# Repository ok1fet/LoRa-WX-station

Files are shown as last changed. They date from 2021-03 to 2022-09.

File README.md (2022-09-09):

<h1>LoRa-APRS-WX-station</h1>
<p>Záměrem bylo vytvořit jednoduchou malou meteosondu. Aby byla levná, aby ji bylo možné bez obav na kopci přidělat na strom :)</p>
<ul>
<p>Informace ze sondy mají sloužit pro piloty paraglidingu, které zajímá hlavně směr a rychlost větru. Proto byla programu věnována značná pozornost. Měření probíhá každých 20 sekund a data se agregují po 5 minutách. Navíc se spočítá průměrná hodnota větru a vyhodnotí se maximální nárazy větru. Směr větru se měří <a href="https://en.wikipedia.org/wiki/Yamartino_method">Yamartino metodou.</a></p>
</ul>  
<p>Data se ukládají na cloudové uložiště na serveru www.aprs.fi.</p>
<p>Pro měření rychlosti a směru větru jsou použita čidla k meteostanici WH1080, která jsou na našem trhu dostupná jako náhradní díly za rozumný peníz.</p>
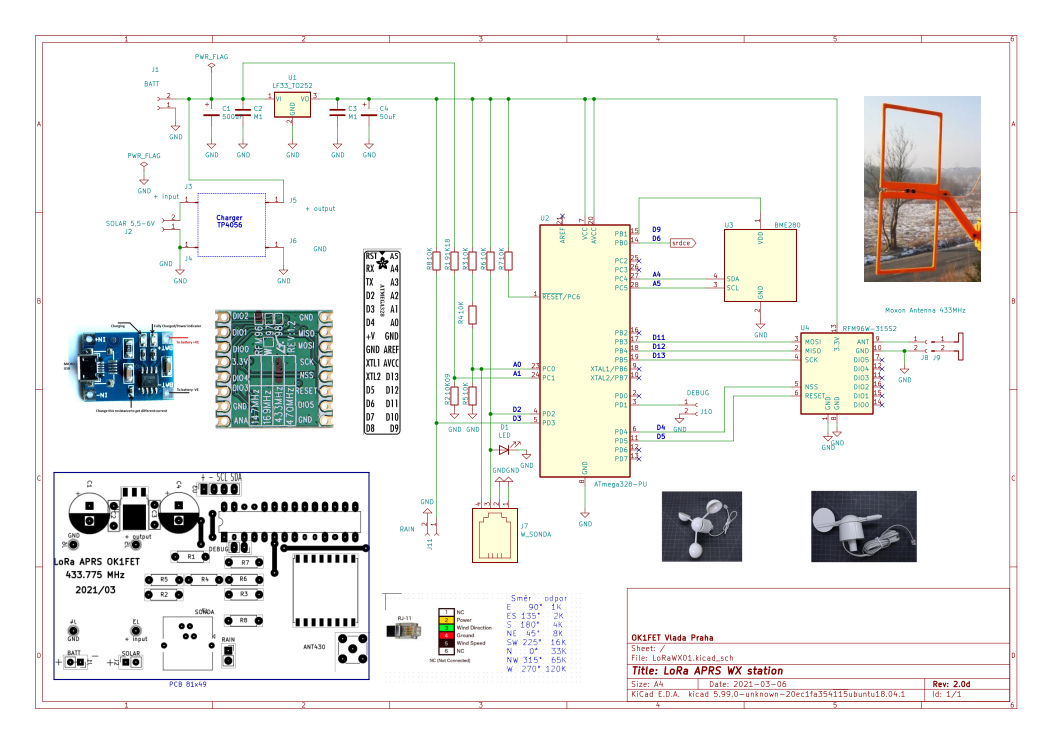
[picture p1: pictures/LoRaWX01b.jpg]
schema
</p>

<p>Meteorologická stanice <a href="http://cukrak.wz.cz/"> Cukrák.</a> Zdrojová data na www.aprs.fi/ok1fet-4.</a></p>
<p>Meteorologická stanice <a href="http://jevinka.wz.cz/"> Jeviněves.</a> Zdrojová data na www.aprs.fi/ok1fet-5.</a></p>
<p>Meteorologická stanice <a href="http://revnicov.wz.cz/"> Řevničov.</a> Zdrojová data na www.aprs.fi/ok1fet-14.</a></p>
<p> Moxon antena na 433MHz. <a href="https://www.thingiverse.com/thing:2068392/files">Zdrojová data</a> pro 3D printer na Thingiverse.</a></p>

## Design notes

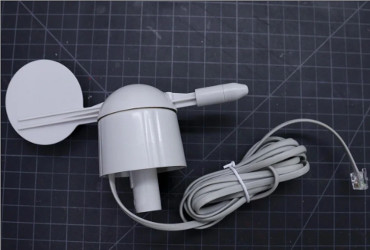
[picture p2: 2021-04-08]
pictures/winddirection.jpg

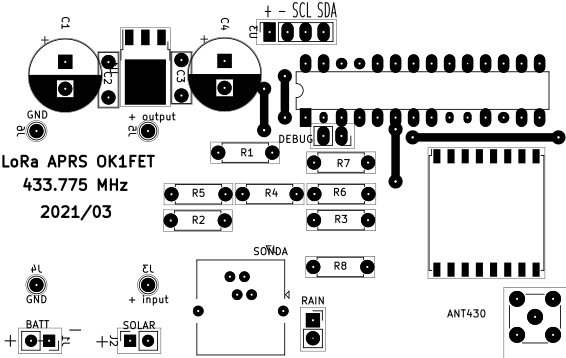
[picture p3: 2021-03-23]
pictures/LoRa_top.jpg

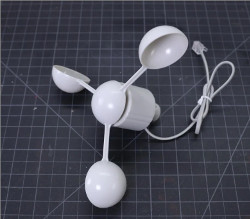
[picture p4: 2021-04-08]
pictures/anemometer.jpg

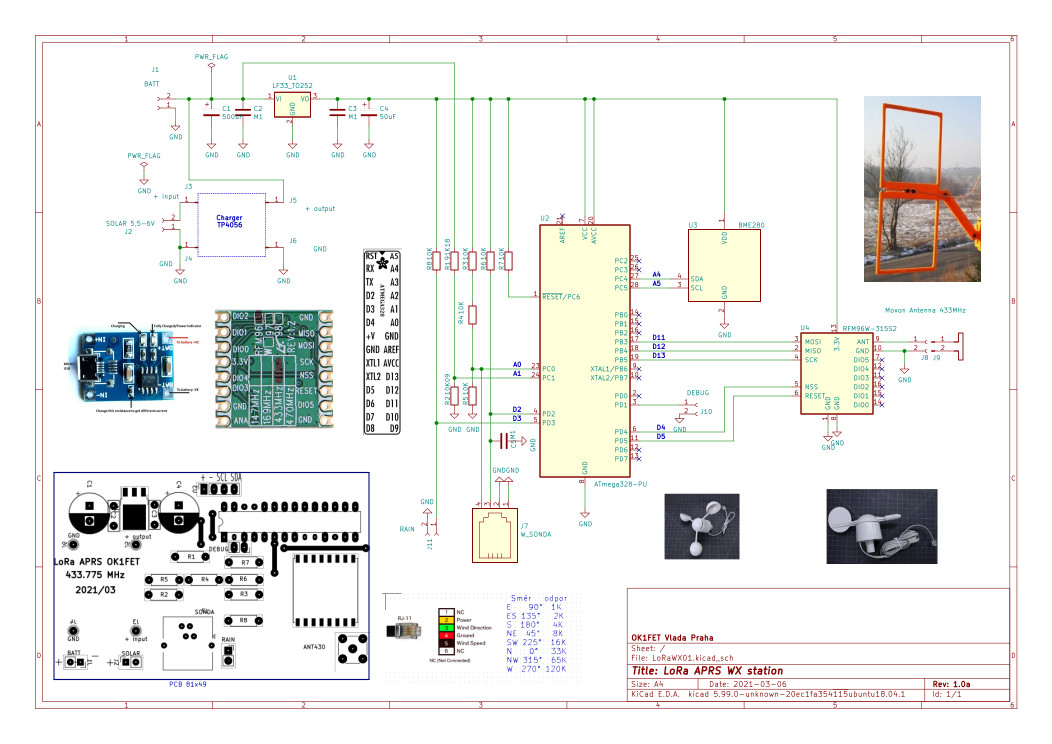
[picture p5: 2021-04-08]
pictures/LoRaWX1a.jpg

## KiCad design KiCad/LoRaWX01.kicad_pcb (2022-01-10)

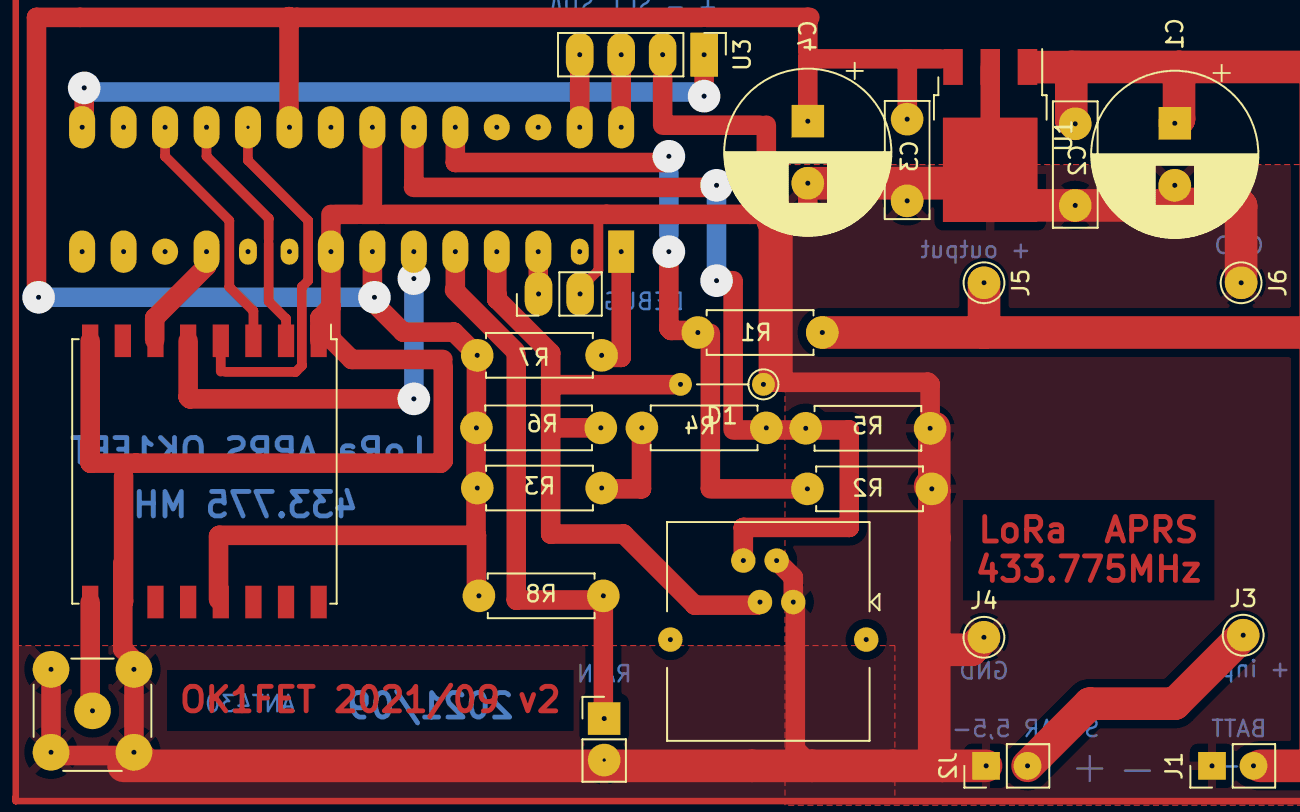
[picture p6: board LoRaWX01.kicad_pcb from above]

Board: 2 copper layers, 27 parts (1 on the bottom side), 20 nets.

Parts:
C1: 500uF; CP_Radial_D10.0mm_P3.80mm
C2: M1; C_Disc_D7.5mm_W2.5mm_P5.00mm
C3: M1; C_Disc_D7.0mm_W2.5mm_P5.00mm
C4: 50uF; CP_Radial_D10.0mm_P3.80mm
D1: LED; R_Axial_DIN0204_L3.6mm_D1.6mm_P5.08mm_Vertical
J1: BATT; PinHeader_1x02_P2.54mm_Vertical
J2: SOLAR 5,5-6V; PinHeader_1x02_P2.54mm_Vertical
J3: + input; Pin_D1.0mm_L10.0mm
J4, J6: GND; Pin_D1.0mm_L10.0mm
J5: + output; Pin_D1.0mm_L10.0mm
J7: W_SONDA; RJ14_Connfly_DS1133-S4_Horizontal
J8: ANT-433; SMA_Molex_73251-2200_Horizontal
J10: DEBUG; PinHeader_1x02_P2.54mm_Vertical
J11: RAIN; PinHeader_1x02_P2.54mm_Vertical
R1: 91K18; R_Axial_DIN0207_L6.3mm_D2.5mm_P7.62mm_Horizontal
R2: 10K09; R_Axial_DIN0207_L6.3mm_D2.5mm_P7.62mm_Horizontal
R3, R4, R5, R6, R7, R8: 10K; R_Axial_DIN0207_L6.3mm_D2.5mm_P7.62mm_Horizontal
U1: LF33_TO252; TO-252-3_TabPin2
U2: ATmega328-PU; DIP-28_W7.62mm
U3: BME280; PinHeader_1x04_P2.54mm_Vertical
U4: RFM96W-315S2; HOPERF_RFM9XW_SMD

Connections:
GND: C1.2, C2.2, C3.2, C4.2, D1.1 (K), J1.1, J2.1, J4.1, J6.1, J7.1, J7.2, J8.2, J10.2, J11.2, R2.2, R5.2, U1.2 (GND), U2.8 (GND), U2.22 (GND), U3.2 (GND), U4.1 (GND), U4.8 (GND), U4.10 (GND)
unnamed: C1.1, C2.1, J1.2, J5.1, R1.1, U1.1 (VI)
unnamed: C3.1, C4.1, R3.1, R6.1, R7.1, R8.1, U1.3 (VO), U2.7 (VCC), U2.20 (AVCC), U4.13 (3.3V)
unnamed: D1.2 (A), J7.3, R6.2, U2.4 (PD2)
unnamed: J2.2, J3.1
unnamed: J7.4, R4.2, R5.1, U2.23 (PC0)
unnamed: J8.1, U4.9 (ANT)
unnamed: J10.1, U2.3 (PD1)
unnamed: J11.1, R8.2, U2.5 (PD3)
unnamed: R1.2, R2.1, U2.24 (PC1)
unnamed: R3.2, R4.1
unnamed: R7.2, U2.1 (~RESET~/PC6)
unnamed: U2.6 (PD4), U4.5 (NSS)
unnamed: U2.11 (PD5), U4.6 (RESET)
unnamed: U2.15 (PB1), U3.1 (VDD)
unnamed: U2.17 (PB3), U4.3 (MOSI)
unnamed: U2.18 (PB4), U4.2 (MISO)
unnamed: U2.19 (PB5), U4.4 (SCK)
unnamed: U2.27 (PC4), U3.4 (SDA)
unnamed: U2.28 (PC5), U3.3 (SCL)

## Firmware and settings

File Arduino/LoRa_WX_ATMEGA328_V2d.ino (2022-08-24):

/* V2d
 * uP ATMEGA328 ja pouzivam bootloader FIO
  * 
 * Pin
 * RFM96  UNO   TTGO
 * SCK    D13   5
 * MISO   D12   19
 * MOSI   D11   27
 * NSS    D4    18    lora_PNSS
 * RST    D5    23    lora_PReset
 * 
 * bme280
 * SCL    A5    
 * SDA    A4
 * 
 */
///////////////////////////////////////////////////////////
//#include "config.h"
#include <LowPower.h>
unsigned int PeriodeCounterSleep = 0; // 2 kdyz je stejne jako "timer" spusti mereni v prvni cyklu
unsigned int timer = 2;               // 2 timer * 8 (SLEEP_8S) = cas buzeni ATMEGA328 sekundy 2 x 8=16sekund
int pocetmereniAgregace = 15;         //15 kolik mereni nez se udela agragace dat cca 5minut
unsigned int cyklus = 0;              //15 kdyz je stejne jako "pocetmereniAgregace" spusti agregace v prvni cyklu

//LoRa
const byte lora_PNSS   = 4;  // 18 pin number where the NSS line for the LoRa device is connected.
const byte lora_PReset = 5;  // 23 pin where LoRa device reset line is connected
const byte PLED1 = 6;        // pin number for LED on Tracker neni zapojeno
#include <SPI.h>
#include "LoRaTX.h"
#include <Wire.h>
String Outstring=""; 
   

// BME280
#include <Adafruit_Sensor.h>
#include <Adafruit_BME280.h>
Adafruit_BME280 bme;
float wind, temp, tempf, humi, pres, pres1;
int napajeni = 9; //pin 15 slouzi pro snizeni spotreby napaji se jen kdyz probiha mereni

// wind speed aneometer
float DataSpeed[30];  // pole pro data
float WindSpeedMax;
float WindSpeedAvg;
int anopin = 3;       // PIN for anemometer input
int InterruptCounter;
float WindSpeed;
int WindSpeedAvgA;// rychlost vetru prumer archiv
int WindSpeedMaxA;// rychlost vetru maximalni archiv
float  wsm,wsa;
volatile unsigned long ContactBounceTime; // Timer to avoid contact bounce in interrupt routine

//wind direction smerova ruzice
#include "Yamartino.h"
Yamartino yamartino(2);   // pocet mereni za sekundu
const int SensorPin = 2;  // Define Interrupt Pin (2 or 3 @ Arduino Uno)
int i=0;

#include "AverageAngle.h"
float DataSmer[30]; // pole pro data
float wdn;  //promena pro prepocet z ADC na uhly
int wd;   // hodnota AD prevodniku
int heading; // promena pro Yamartino knihovnu
float wda;    // WindDirectoryArchiv
float WindDirectoryAvg; // vystupni hodnota z AverageAngle
int pinWindDir = A0;//pin pro smer vetru

//mereni baterie
int voltPin = A1;
float vcc;
float predradnik;
float adc;
float napetiCPU = 1.1;   // hodnoto napajeciho napeti uProcesoru analogReference(INTERNAL)1.1V

char sentence[150];

int srdce = 8; //pin 14 vystup pro HW reset
int srdce_status = 0;

const char* station = "OK1XYZ-11>APRS:!5004.91N/01431.53E_"; // upravit call!!!!!
float ELEVATION = 224; // viska metru nad morem
float resistor1 = 90.92; // 90K pro 8,5V vstupni svorka 
float resistor2 = 10.08;  // 10Kohm na GND

/////////////////////////////////////////////////////////////////////////////////////////
void setup()
{
  analogReference(INTERNAL);
  predradnik = resistor2 / (resistor1 + resistor2);
  
  Serial.begin(9600);  
  Serial.println("start_v2d");// 
  delay(20);

  pinMode(napajeni, OUTPUT); // napajeni pro BME280

  pinMode(lora_PReset, OUTPUT);     // RFM98 reset line
  digitalWrite(lora_PReset, LOW);   // Reset RFM98
  pinMode (lora_PNSS, OUTPUT);      // set the slaveSelectPin as an output:
  digitalWrite(lora_PNSS, HIGH);
  pinMode(PLED1, OUTPUT);                                                          // for shield LED neni na pcb sviti pri TX
  
  SPI.begin();                                                                     // initialize SPI:
  SPI.setClockDivider(SPI_CLOCK_DIV2);
  SPI.setDataMode(SPI_MODE0);
  SPI.setBitOrder(MSBFIRST);
   
   lora_ResetDev();                                                                 // Reset the device
   lora_Setup();                                                                    // Do the initial LoRa Setup

// LoRa frequency calculation (sample for 434.4 MHz): 
// ------------------------------------
// 434400000/61.03515625 = 71172096
// 71172096 (DEC) = 6C 99 99 (HEX)  
// 6C 99 99 (HEX) = 108 153 153 (DEC)  

   lora_SetFreq(108, 113, 153);  // Set the LoRa frequency, 433.775 Mhz

   

pinMode(srdce, OUTPUT);  
}

///////////////////////////////////////////////////////////////////////////////////////
void loop(){
  
  while(PeriodeCounterSleep < timer){
  Serial.println("+");
  PeriodeCounterSleep++;
  delay(100);
  LowPower.powerDown(SLEEP_8S, ADC_OFF, BOD_OFF); 
   }
PeriodeCounterSleep = 0; 
/*****************************************************************
                     5 minut cyklus Agregace dat
*****************************************************************/
if (cyklus >= pocetmereniAgregace){
Serial.println("5 minut cyklus Agregace dat + odeslani dat LoRa"); 
/*****************************************************************/
digitalWrite(srdce, HIGH); 
digitalWrite(napajeni, HIGH); 
  for (i=0;i<cyklus;i++){
  //Serial.println(DataSpeed[i]); 
   WindSpeedAvg = (DataSpeed[i])+ WindSpeedAvg; // secte vsechny hodnoty v poly DataSpeed
  
  if ((DataSpeed[i]) > WindSpeedMax){     // pri listovani pole DataSpeed hleda maximalni hodnotu
  //Serial.println("Vyhodnoceni WindSpeedMax") ;
    WindSpeedMax=(DataSpeed[i]) ;     // zapise maximalni hodnotu do promene WindSpeedMax
  }
}
WindSpeedAvg = WindSpeedAvg / cyklus; // vypocita prumernou hodnotu WindSpeedAvg

/*****************************************************************/  
AverageAngle Smer(AverageAngle::DEGREES);
  Smer.reset();
  for (i=0;i<cyklus;i++){     //cyklus precte pole DataSmer a pomoci knihovny vypocitá průmerný úhel
      Smer.add(DataSmer[i]);
  }
  WindDirectoryAvg = Smer.getAverage();

/**************************************************************/  
// zmeri napeti 
  vcc = analogRead(voltPin);
// Convert to actual voltage (0 - 1.1 V internal)
  vcc = (vcc / 1024) * napetiCPU;
  vcc = vcc / predradnik;

  bme.begin(0x76); //address either 0x76 or 0x77
  bme.takeForcedMeasurement();
  temp = bme.readTemperature();
  humi = bme.readHumidity();
  pres = (bme.readPressure())/pow((1-ELEVATION/44330.0), 5.255)/10;// prepocet tlaku na hladinu more
  
  wda = Smer.getAverage();
  wsa = WindSpeedAvg;
  wsm = WindSpeedMax;
  digitalWrite(napajeni, LOW); 
  
   byte i;
   byte ltemp;
   tempf=(temp*1.8)+32; // celsius to fahrenheit

    
// prezentace dat
  Serial.println("") ;
  Serial.print("Average Direction = ");
  Serial.print(wda,0); 
  Serial.println("°") ;

  Serial.print("Wind Speed Avg    = ");
  Serial.print(wsa,1);       //Speed in mph
  Serial.println(" mph"); 
    
  Serial.print("Wind Speed Max    = ");
  Serial.print(wsm,1);       //Speed in mph
  Serial.println(" mph");

  Serial.print("Napeti            = ");
  Serial.print(vcc);
  Serial.println("V");
  
  Serial.print("Temperature       = ");
  Serial.print(temp,1);
  Serial.println("°C");
  
  Serial.print("Humidity          = ");
  Serial.print(humi,0);
  Serial.println("%");
  pres1=pres/10;
  Serial.print("Pressure to sea   = ");
  Serial.print(pres1,1);
  Serial.println("hPa");
  


// odeslani dat pres LoRa 
   Outstring = (station); 
   if(wda<99) { Outstring += "0"; }
   if(wda<9)  { Outstring += "0"; }
   Outstring += String(wda,0);
   Outstring += "/";
   if(wsa<99) { Outstring += "0"; }
   if(wsa<9)  { Outstring += "0"; }
   Outstring += String(wsa,0);
   Outstring += ("g");
   if(wsm<99) { Outstring += "0"; }
   if(wsm<9)  { Outstring += "0"; }
   Outstring += String(wsm,0);
   Outstring += ("t");
   if(tempf<99) { Outstring += "0"; }
   if(tempf<9) { Outstring += "0"; }
   Outstring += String(tempf,0);
   Outstring += ("h");
   Outstring += String(humi,0);
   Outstring += ("b");
   if(pres<999) { Outstring += "0"; }
   Outstring += String(pres,0);
   Outstring += ("_BATT=");
   Outstring += String(vcc,2);
   Outstring += ("V");

   if (srdce_status == 0){
    Outstring += ("_RESETd");
    srdce_status = 1;
   }

   Serial.print("sending: ");
   //Serial.println(Outstring);
   Outstring.replace(" ","");// wsa a wda pri zaukrohlovani obcas vkladji mezeru pred hodnotu!
   Serial.println(Outstring);
 

//LoRa
    ltemp = Outstring.length();
    lora_SetModem(lora_BW125, lora_SF12, lora_CR4_5, lora_Explicit, lora_LowDoptON);    // Setup the LoRa modem parameters
    lora_PrintModem();                                                                  // Print the modem parameters
    lora_TXStart = 0;
    lora_TXEnd = 0;
    for (i = 0; i <= ltemp; i++)
    {
    lora_TXBUFF[i] = Outstring.charAt(i);
    }
    i--;
    lora_TXEnd = i;    
    digitalWrite(PLED1, HIGH);  // LED ON on during sending
    
    Serial.print("ON AIR");

    lora_Send(lora_TXStart, lora_TXEnd, 60, 255, 1, 10, 17);  
    digitalWrite(PLED1, LOW);   // LED OFF after sending
    lora_TXBuffPrint(0);
//konec vysilani dat LoRa     
 
    Outstring = "";
    cyklus = 0;
    WindSpeedAvg = 0;
    WindSpeedMax = 0;
    digitalWrite(srdce, LOW); 
   
/**************konec 5 minutoveho i cyklu************************************************/  
}
/*****************************************************************
                 standardni mereni kazdych 20 sekund
*****************************************************************/
    Serial.print(cyklus);
    Serial.println(" - standardni mereni kazdych 20 sekund");
    digitalWrite(srdce, HIGH); 
    mereniWindSpeed();
    DataSpeed[cyklus]=(WindSpeed);// zapise hodnotu do pole DataSpeed

    heading = getWindDirection();
    yamartino.add(heading);
    DataSmer[cyklus] = (yamartino.averageHeading());// zapise hodnotu do pole DataSmer

    Serial.print(WindSpeed,1); //Speed in mph
    Serial.println(" mph");
    Serial.print(yamartino.averageHeading(),0);
    Serial.println("°") ;
    Serial.println("ulozeno do datoveho pole");
    Serial.println("goto Sleeping...");
    digitalWrite(srdce, LOW); 
    delay (100);


cyklus++;
}// endloop
/*****************************************************************
                 mereni rychlosti vetru
*****************************************************************/
void mereniWindSpeed() {
    InterruptCounter = 0; // Set Rotations count to 0 ready for calculations 
    attachInterrupt(digitalPinToInterrupt(SensorPin), countup, FALLING);
    delay(3000);// Wait 3 seconds to average 
    detachInterrupt(digitalPinToInterrupt(SensorPin));
//  WindSpeed = (float)InterruptCounter / 3 * 1.492;// prepocet na Mph 0,497333333(prepocet z ms na Mph) / 3 (delka mereni v sekundach)
//  WindSpeed = (float)InterruptCounter * 0.3 ;// vranova konstanta --> ukazuje mene!!!
// prepocet 3 vteriny rotace na MPh
         if ((float)InterruptCounter   <= 42){WindSpeed = (float)InterruptCounter /3 * 0.77;}
    else if ((float)InterruptCounter   <= 45){WindSpeed = (float)InterruptCounter /3 * 0.82;}
    else if ((float)InterruptCounter   <= 48){WindSpeed = (float)InterruptCounter /3 * 0.87;}
    else if ((float)InterruptCounter   <= 51){WindSpeed = (float)InterruptCounter /3 * 0.90;}
    else if ((float)InterruptCounter   <= 54){WindSpeed = (float)InterruptCounter /3 * 0.94;}
    else if ((float)InterruptCounter   >= 55){WindSpeed = (float)InterruptCounter /3 * 0.89;}
}

void countup() {
if ((millis() - ContactBounceTime) > 15 ) { // osetreni zakmitavani jazyckoveho kontaktu 
InterruptCounter++;
ContactBounceTime = millis(); 
}   
  
}
/*****************************************************************
                 mereni smeru vetru
*****************************************************************/
float getWindDirection() {

   wd =  analogRead(pinWindDir);
delay(10);
// Serial.print("WindDir");// pouzit pro kalibraci smerove ruzice
// Serial.println(wd);

      if      (wd < 150) wdn =  90; 
      else if (wd < 270) wdn = 135; 
      else if (wd < 400) wdn = 180; 
      else if (wd < 580) wdn =  45; 
      else if (wd < 760) wdn = 225; 
      else if (wd < 890) wdn =   0; 
      else if (wd < 960) wdn = 315; 
      else if (wd < 1000)wdn = 270;       
  
  return wdn;  
}
/* REMARKS
zapise bootloader nastavi pojistky 8MHz vnitrni hodiny na pin19 D13 blika 1S programovat Arduino FIO
avrdude -c arduino -p m328p -b 19200 -P /dev/ttyACM0 -U flash:w:ATmegaBOOT_168_atmega328_pro_8MHz.hex -Uefuse:w:0xFD:m -Uhfuse:w:0xDA:m -Ulfuse:w:0xE2:m

https://weather.gladstonefamily.net/aprswxnet.html
 
Field  Meaning
CW0003  Your CW number
>APRS,TCPIP*: Boilerplate
/241505z  The ddhhmm in UTC of the time that you generate the report. However, the timestamp is pretty much ignored by everybody as it is assumed that your clock is not set correctly! If you want to omit this field, then just send an exclamation mark '!' instead.
4220.45N/07128.59W  Your location. This is ddmm.hh -- i.e. degrees, minutes and hundreths of minutes. The Longitude has three digits of degrees and leading zero digits cannot be omitted.
_032  The direction of the wind from true north (in degrees).
/005  The average windspeed in mph
g008  The maximum gust windspeed in mph (over the last five minutes)
t054  The temperature in degrees Farenheit -- if not available, then use '...' Temperatures below zero are expressed as -01 to -99.
r001  The rain in the last 1 hour (in hundreths of an inch) -- this can be omitted
p078  Rain in the last 24 hours (in hundreths of an inch) -- this can be omitted
P044  The rain since the local midnight (in hundreths of an inch) -- this can be omitted
h50 The humidity in percent. '00' => 100%. -- this can be omitted.
b10245  The barometric pressure in tenths of millbars -- this can be omitted. This is a corrected pressure and not the actual (station) pressure as measured at your weatherstation. The pressure is adjusted according to altimeter rules -- i.e. the adjustment is purely based on station elevation and does not include temperature compensation.
 
OK1FET-5>APN100,TCPIP*:=5020.55N/01419.98E_045/002g...t045r...p...P000h55b.....eESP8266
 
ANT 433MHz
https://quadmeup.com/3d-printed-433mhz-moxon-antenna-with-arm-and-snap-mount/
https://www.thingiverse.com/thing:2068392/files
 
lf33
http://robodoupe.cz/2012/vezmu-lf33-a-zadny-problem/
https://ok1kvk.cz/clanek/2017/LF33-aneb-ctete-datasheety/

Lithium Battery charging tp4056
https://www.buildcircuit.com/how-to-use-micro-usb-5v-1a-lithium-battery-charging-board-charger-module/
http://jimlaurwilliams.org/wordpress/?p=4731

bme280 how AMSL
https://www.meteocercal.info/forum/Thread-How-to-get-the-sea-level-pressure-with-BMP280

inspirace
https://www.instructables.com/Solar-Powered-WiFi-Weather-Station-V30/?utm_source=newsletter&utm_medium=email

prevest WGS84  N 50°10.84313', E 13°53.28152'zapsat jako 5010.84N/01353.28E

 */

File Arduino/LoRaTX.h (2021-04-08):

/*
**************************************************************************************************
ProMiniLoRaTracker_V1 Programs

Copyright of the author Stuart Robinson - 02/07/2015 15:00

These programs may be used free of charge for personal, recreational and educational purposes only.

This program, or parts of it, may not be used for or in connection with any commercial purpose without
the explicit permission of the author Stuart Robinson.

The programs are supplied as is, it is up to individual to decide if the programs are suitable for the
intended purpose and free from errors.
**************************************************************************************************
*/


//http://www.kh-gps.de/LoRa_WX.htm

/*
**************************************************************************************************
Variable definitions
**************************************************************************************************
*/

//byte Variables
byte  lora_TXStart;				//start of packet data in TXbuff
byte  lora_TXEnd;				//end of packet data in TXbuff
byte  lora_FTXOK;				//flag, set to 1 if TX OK
byte  lora_TXPacketType;		//type number of packet to send
byte  lora_TXDestination;		//destination address of packet to send
byte  lora_TXSource;			//source address of packet received
byte  lora_FDeviceError;		//flag, set to 1 if RFM98 device error
byte  lora_TXPacketL;			//length of packet to send, includes source, destination and packet type.

//byte arrays
byte  lora_TXBUFF[128];			//buffer for packet to send

//Integer variables, more than byte
long lora_TXpacketCount;		//count of packets sent

//Float Variables
double lora_Frequency;			//last programmed frequency



/*
**************************************************************************************************
Constant definitions
**************************************************************************************************
*/

//LoRa names for bandwidth settings
const byte lora_BW7_8 = 0;      //7.8khz
const byte lora_BW10_4 = 16;    //10.4khz
const byte lora_BW15_6 = 32;    //15.6khz
const byte lora_BW20_8 = 48;    //20.8khz
const byte lora_BW31_2 = 64;    //31.2khz
const byte lora_BW41_7 = 80;    //41.7khz
const byte lora_BW62_5 = 96;    //62.5khz
const byte lora_BW125 = 112;    //125khz
const byte lora_BW250 = 128;    //250khz
const byte lora_BW500 = 144;    //500khz

//Spreading Factors
const byte lora_SF6 = 6;
const byte lora_SF7 = 7;
const byte lora_SF8 = 8;
const byte lora_SF9 = 9;
const byte lora_SF10 = 10;
const byte lora_SF11 = 11;
const byte lora_SF12 = 12;

//LORA names for coding rate settings
const byte lora_CR4_5 = 2;	//4:5
const byte lora_CR4_6 = 4;	//4:6
const byte lora_CR4_7 = 6;	//4:7
const byte lora_CR4_8 = 8;	//4:8

//LORA Header Settings
const byte lora_Explicit    = 0;	//Use to set explicit header
const byte lora_Implicit    = 1;	//Use to set implicit header

//Misc definitions
const byte lora_Deviation = 0x52;
const byte lora_LowDoptON = 0x08;       //value to turn low data rate optimization on
const byte lora_LowDoptOFF = 0x00;      //value to turn low data rate optimization off
const byte lora_PrintASC = 0;           //value to cause buffer print to appear as ASCII
const byte lora_PrintNum = 1;           //value to cause buffer print to appear as decimal numbers
const byte lora_PrintHEX = 2;           //value to cause buffer print to appear as hexadecimal numbers


//SX1278 Register names
const byte lora_RegFifo = 0x00;
const byte lora_WRegFifo = 0x80;
const byte lora_RegOpMode = 0x01;
const byte lora_RegFdevLsb = 0x05;
const byte lora_RegFrMsb = 0x06;
const byte lora_RegFrMid = 0x07;
const byte lora_RegFrLsb = 0x08;
const byte lora_RegPaConfig = 0x09;
const byte lora_RegOcp = 0x0B;
const byte lora_RegLna = 0x0C;
const byte lora_RegFifoAddrPtr = 0x0D;
const byte lora_RegFifoTxBaseAddr = 0x0E;
const byte lora_RegIrqFlagsMask = 0x11;
const byte lora_RegIrqFlags = 0x12;
const byte lora_RegRxNbBytes = 0x13;
const byte lora_RegRxHeaderCntValueMsb = 0x14;
const byte lora_RegRxHeaderCntValueLsb = 0x15;
const byte lora_RegRxPacketCntValueMsb = 0x16;
const byte lora_RegRxPacketCntValueLsb = 0x17;
const byte lora_RegPktSnrValue = 0x19;
const byte lora_RegPktRssiValue = 0x1A;
const byte lora_RegRssiValue = 0x1B;
const byte lora_RegFsiMSB = 0x1D;
const byte lora_RegFsiLSB = 0x1E;
const byte lora_RegModemConfig1 = 0x1D;
const byte lora_RegModemConfig2 = 0x1E;
const byte lora_RegSymbTimeoutLsb = 0x1F;
const byte lora_RegPreambleLsb = 0x21;
const byte lora_RegPayloadLength = 0x22;
const byte lora_RegFifoRxByteAddr = 0x25;
const byte lora_RegModemConfig3 = 0x26;
const byte lora_RegPacketConfig2 = 0x31;
const byte lora_TXdefaultpower = 10;



/*
**************************************************************************************************
Library Functions
**************************************************************************************************
*/

void lora_ResetDev()
{
  //resets the LoRa device
  //Serial.print("LORA.ResetDev()");
  //Serial.println();
  digitalWrite(lora_PReset, LOW);		// take reset line low
  delay(5);
  digitalWrite(lora_PReset, HIGH);	// take it high
}



void lora_Write(byte lora_LReg, byte lora_LData)
{
  //write a byte to a LoRa register
  //Serial.print("lora_Write() ");
  //lora_PrintAsHEX(lora_LReg);
  //Serial.print(" ");
  //lora_PrintAsHEX(lora_LData);
  //Serial.println();
  digitalWrite(lora_PNSS, LOW);		// set NSS low
  SPI.transfer(lora_LReg | 0x80);		// mask address for write
  SPI.transfer(lora_LData);			// write the byte
  digitalWrite(lora_PNSS, HIGH);			// set NSS high
}


byte lora_Read(byte lora_LReg)
{
  //read a byte to a LoRa register
  //Serial.print("lora_Read()");
  //Serial.println();
  byte lora_LRegData;
  digitalWrite(lora_PNSS, LOW);		// set NSS low
  SPI.transfer(lora_LReg & 0x7F);		// mask address for read
  lora_LRegData = SPI.transfer(0);	// read the byte
  digitalWrite(lora_PNSS, HIGH);		// set NSS high
  return lora_LRegData;
}

void lora_SetFreq(byte lora_LFMsb, byte lora_LFMid, byte lora_LFLsb)
{
  lora_Write(lora_RegFrMsb, lora_LFMsb);
  lora_Write(lora_RegFrMid, lora_LFMid);
  lora_Write(lora_RegFrLsb, lora_LFLsb);
}

void lora_Setup()
{
  //initialize LoRa device registers and check its responding
  //Serial.print("lora_Setup()");
  //Serial.println();
  lora_ResetDev();								// Clear all registers to default
  lora_Write(lora_RegOpMode, 0x08);				// RegOpMode, need to set to sleep mode before configure for LoRa mode
  lora_Write(lora_RegOcp, 0x0B);					// RegOcp
  lora_Write(lora_RegLna, 0x23);					// RegLna
  lora_Write(lora_RegSymbTimeoutLsb, 0xFF);		// RegSymbTimeoutLsb
  lora_Write(lora_RegPreambleLsb, 0x0C);			// RegPreambleLsb, default
  lora_Write(lora_RegFdevLsb, lora_Deviation);	// LSB of deviation, 5kHz

}
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
